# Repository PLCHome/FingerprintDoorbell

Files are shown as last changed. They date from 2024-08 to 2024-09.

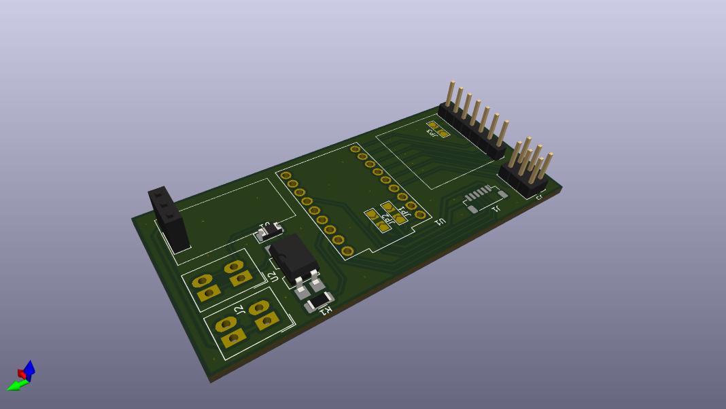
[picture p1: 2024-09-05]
PCBprints/Fingerprint_doorbell.jpg

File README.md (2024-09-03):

# FingerprintVoipDoorbell

## What is FingerprintVoipDoorbell?
It's more or less a doorbell with the ability to scan finger prints or a fingerprint reader with the ability to act as doorbell, depending on your perspective ;-). In addition, if your fingerprints are unknown, you can call and speak to you. Carry out additional actions using telephone keys. The number can be changed to the cell phone if the alarm system is armed, for example. And then when it's the postman the garage opens over the phone using e.g. * or something like that.

But lets speak some images:






## How does it work?
If you put your finger on the sensor the system looks for a matching fingerprint. If it doesn't find one, it rings the bell (MQTT message is published and an GPIO pin is set to high). The system also starts a phone call to a stored number. If a call is made, MQTT messages can be triggered via the number keys on the phone, which in combination with home automation solution (like OpenHAB, ioBroker, Home Assistant...) can be used to open a garage door for the postman to drop off packages, for example, or a smart lock for the child without a key.
If a match was found, the matching finger ID together with a name and confidence will be published as MQTT messagage. In combination with a home automation solution (like OpenHAB, ioBroker, Home Assistant...) you can then trigger your door opener or smart lock. You can also define actions depending on the finger that was detected, like left thumb opens front door, right thumb opens garage, middle finger...

## Features 

### voip:
- Switching off the voip via MQTT (no calls e.g. at night)
- Internal/external number switching via MQTT (e.g. when alarm system is armed/disarmed)
- Ending a call that has not been established via MQTT, e.g. when the door is opened.
- Ending the call when the door is opened.
- Sending key presses via MQTT during an existing telephone call. (e.g. to open the garage)

### fingerprint:
- Management of up to 100 fingers from different people
- Sending the number and recognition code of the recognized finger
- Triggering an output to switch a relay to trigger the alarm if no finger is recognized.
- Starting a call via VoIP if no finger is recognized.
- Ending the call again if the finger is recognized

## Is it from me?
This implementation is not mine alone, it was put together from different branches and revised a little.
- It is an fork on the FingerprintDoorBell from Frickelzeugs:
    
    https://github.com/frickelzeugs/FingerprintDoorbell

- The changes from TheMaskedDeveloper were also adopted for MQTT and the color in the ring.
    
    https://github.com/TheMaskedDeveloper/FingerprintDoorbell/tree/master

- It got the sources and circuitry from Voip Doorbell from Jens Weißkopf for call initiation and audio:

    https://github.com/weisskopfjens/esp32voipdoorbell

    This is based on:
    sip.cpp copyright (c) 2018 Juergen Liegner

      https://www.mikrocontroller.net/topic/444994

Many thanks to everyone for being able to implement this so quickly. It was easy going because of your great work.

## What do I need?
- fingerprint reader Grow R503
- microphone inmp 441
- amplifier max98357 i2s 3w
- speakers with 3w
- an ESP32 microcontroller (I would prefer the mini-version, because of it's compact size).

# How to build the hardware
## Wiring

|ESP32 GPIO | Connected to | notes |
|---|---|---|
|I2S Amplifier| | |
|14 | BCLK | |
|12 | LRC | |
|27 | DIN | |
|I2S Mic | | |
|26 | BCKL SCK | |
|25 | LRCL WS | |
|33 | DOUT SD | |
|Bell | | |
|19 | Ring 2sec. | |
|R503 | | |
|17 | RXD R503 | |
|16 | TXD R503 | |
|5 | WAKEUP R503  | |

Example R503:



I would not solder the cables directly to the ESP32 but recommend using a connector between ESP32 and Sensor. Otherwise, the cables must first be fed through the 25mm hole for the sensor and then soldered on. Replacing the Sensor will be a pain then. The original plug used on the sensor is a 6-pin Micro JST SH 1.00mm but it'll be fine to use any other 6-pin connector that you have on hand if you replace both sides.

Just as an inpiration:



I made a small shield board for the ESP32 mini that contains a 6 pin Micro JST SH 1.00mm socket, a DC-DC step down converter and some screw terminals for the power supply (in my case 24V DC). So I'm now able to easily replace the sensor or ESP32 without touching my soldering iron.

Caution: Please do not forget to ground the sensor housing. Otherwise it can lead to unexpected restarts or even damages the ESP32 if you are electrostatically charged. I had occasional restarts when touching the sensor after I was electrostatically charged from the floor mats in the car.

# Flashing the firmware
## Method 1: use precompiled binaries
To flash the ESP32 with the precompiled binaries you can use the python based esptool from espressif. You'll need a running Python environment on your system, so get Python first here if you don't already have it: [Python download](https://www.python.org/downloads/)

After python is available run the following command in your shell/cmd to install esptool:
```
pip install esptool
```
If there is a `command not found: pip` error but you have installed Python try to use pip3 insted of pip.
```
pip3 install esptool
```

Now esptool should be available in your shell/cmd. Check it by running:
```
esptool.py
```

Now that esptool.py is available you can continue to flash the firmware. To start you will need 5 files:

- bootloader_dio_40m.bin
- boot_app0.bin
- partitions.bin

download [here](doc/bootloader.zip)

- firmware.bin
- spiffs.bin

contained in the [Release packages](releases)

### Flashing
Copy all 5 files in a local folder, open your command line/shell, navigate to this folder and execute:

```
esptool.py --chip esp32 --baud 460800 --before default_reset --after hard_reset write_flash -z --flash_mode dio --flash_freq 40m --flash_size detect 0x1000 bootloader_dio_40m.bin 0x8000 partitions.bin 0xe000 boot_app0.bin 0x10000 firmware.bin 2686976 spiffs.bin
```

If everything has worked your output should look something like this:

```
esptool.py v3.2
Found 2 serial ports
Serial port COM4
Connecting....
Chip is ESP32-D0WDQ6 (revision 1)
Features: WiFi, BT, Dual Core, 240MHz, VRef calibration in efuse, Coding Scheme None
Crystal is 40MHz
MAC: 9c:9c:1f:c7:ac:a0
Uploading stub...
Running stub...
Stub running...
Changing baud rate to 460800
Changed.
Configuring flash size...
Auto-detected Flash size: 4MB
Flash will be erased from 0x00001000 to 0x00005fff...
Flash will be erased from 0x00008000 to 0x00008fff...
Flash will be erased from 0x0000e000 to 0x0000ffff...
Flash will be erased from 0x00010000 to 0x00121fff...
Flash will be erased from 0x00290000 to 0x003fffff...
Compressed 17104 bytes to 11191...
Wrote 17104 bytes (11191 compressed) at 0x00001000 in 0.6 seconds (effective 225.1 kbit/s)...
Hash of data verified.
Compressed 3072 bytes to 128...
Wrote 3072 bytes (128 compressed) at 0x00008000 in 0.1 seconds (effective 300.7 kbit/s)...
Hash of data verified.
Compressed 8192 bytes to 47...
Wrote 8192 bytes (47 compressed) at 0x0000e000 in 0.1 seconds (effective 463.9 kbit/s)...
Hash of data verified.
Compressed 1119504 bytes to 666873...
Wrote 1119504 bytes (666873 compressed) at 0x00010000 in 16.1 seconds (effective 555.0 kbit/s)...
Hash of data verified.
Compressed 1507328 bytes to 36014...
Wrote 1507328 bytes (36014 compressed) at 0x00290000 in 7.5 seconds (effective 1599.3 kbit/s)...
Hash of data verified.

Leaving...
Hard resetting via RTS pin...
```

Your device should now boot up and the LED ring should start flashing slowly red ("breathing") to signal that it's currently in WiFi Config mode. Proceed with the configuration of the device.

## Method 2: build and flash with Visual Studio Code and PlattformIO
Method 1 is the prefered way if you just want a ready to use version of your FingerprintVoipDoorbell. But if you want to build it on your own or maybe modify the code in some way to fit your needs please follow the instructions below. I don't want to go into details here and assume that you already have experience with IDEs or using Git repos:
* Download and install [Visual Studio Code and PlattformIO Extension](https://platformio.org/platformio-ide).
* Install [Git](https://git-scm.com/downloads) if you don't have already
* Clone this GitHub repo and open the project workspace in VS Code (you can do this in one step from within VS Code)
* Open the PlatformIO extension from the left sided toolbar and from the "Project Tasks" tree choose
  * esp32doit-devkit-v1 -> General -> Build (creates firmware.bin)
  * esp32doit-devkit-v1 -> Platform -> Build Filesystem Image (creates spiffs.bin containing HTML and CSS files)
* if the build finishes successfully you can start uploading to your ESP32 by using the following tasks
  * esp32doit-devkit-v1 -> General -> Upload
  * esp32doit-devkit-v1 -> Platform -> Upload Filesystem Image

# Configuration
## WiFi Connection
If no WiFi settings are configured (e.g. on a fresh install) the device will automatically boot into WiFi configuration mode (LED ring is breathing red). Once your WiFi connection is configured the device will never enter WiFi config mode again, even if the WiFi is not available or it cannot connect because of errors. If you later want to enter WiFi configuration mode again you have to press and hold your finger at least 10s on the sensor while powering on the device (or trigger a reboot through WebUI). 

When in WiFi config mode FingerprintVoipDoorbell will act as an AccessPoint an creates it's own Network with the Name "FingerprintVoipDoorbell-Config". Connect to this network with your PC/Mobile and Password "12345678". You should then get a "captive portal" notification, which you should bring you to the browser with the WiFi config already open. If the captive portal thing does not work please open a browser manually and visit "http://192.168.4.1".



Enter your settings and click "Save and restart" to bring the device back to normal operation mode. If everything had worked the LED ring should first flash blue while bootup and starts breathing blue if connection to your WiFi is running. When connected to your WiFi the WebUI of Fingerprintdoorbell should be available under http://fingerprintdoorbell (if you used the default hostname in WiFi configuration). Now you can start enrolling ("teaching") your fingerprints.

## Managing fingerprints
The sensor has the capacity for storing up to 200 fingerprints. Theses memory slots are used as ID together with a name to increase human readability. To enroll new fingerprints enter a ID and name (optional) in the "Add/Replace fingerprint" section and click "Start enrollment". Now the system asks you to place and lift your finger to the sensor for 5 times. The 5 passes of scanning helps the sensor to improve its recognition rate. Don't try to vary your placing/position too much, because the enrollment process may fail if the 5 preceeding scans differ too much from each other and cannot be combined to one fingerprint template.



If enrollment has completed successfull you can now test if your fingerprint matches.

## Configure MQTT connection
Matching fingerprints (and also ring events) are published as messages to your MQTT broker at certain topics. For this you will have to configure your MQTT Broker settings in FingerprintVoipDoorbell. If your broker does not need authentification by username and password just leave this fields empty. You can also specify a custom root topic under which FingerprintVoipDoorbell publishes its messages or leave the default "fingerprintVoipDoorbell" if you're fine with that.



| MQTT Topic | Action | Values | Comment |
| --- | --- | --- | --- |
| fingerprintVoipDoorbell/ring | publish | "off" by default | On a ring event switching to "on" for 1s | 
| fingerprintVoipDoorbell/matchId | publish | "-1" by default |If a match was found the value holds the matching id (e.g. "27") for 3s | 
| fingerprintVoipDoorbell/matchName | publish | "" by default | If a match was found the value holds the matching name for 3s | 
| fingerprintVoipDoorbell/matchConfidence  | publish | "" by default | If a match was found the value holds the conficence (number between "1" and "400", 1=low, 400=very high) for 3s |
| fingerprintVoipDoorbell/phoneSignal  | publish | "0"-"9", "*", "#"  | The phone buttons are pressed when a call is in progress.|
| fingerprintVoipDoorbell/phoneSignalDuration  | publish | "100" in ms | The time it takes to press a button on VoIP telephones is normally 100ms|
| fingerprintVoipDoorbell/ignoreTouchRing  | subscribe | "on", "off" | Read by FingerprintVoipDoorbell and enables/disables the touch ring (see FAQ below for details) |
| fingerprintVoipDoorbell/hangup  | subscribe | "hangup" |Hanging up the phone when talking or ringing. E.g. when the door is opened. |
| fingerprintVoipDoorbell/useNumber  | subscribe | "intern", "extren", "nocall" |Changing the phone number, for example, to external when the alarm system is armed or to off at night so that only the bell does not ring. |

## Advanced Actions
### Firmware Update
If you've managed to walk the bumpy path of flashing the firmware on the ESP32 for the first time, dont't worry: every further firmware update will be a piece of cake. FingerprintVoipDoorbell is using the really cool Library [AsyncElegantOTA](https://github.com/ayushsharma82/AsyncElegantOTA) to make this as handy as possible. You don't even have to pull the microcontroller out of the wall and connect it to your computer, because the "OTA" in "AsyncElegantOTA" is for "Over-the-air" updates. All you need to do is to browse to the settings page of the WebUI and hit "Firmware update". In the following Dialog you have to upload 2 files

- firmware.bin for the "Firmware" radio button
- spiffs.bin for the "Filesystem" radio button

Done. Reboot your system to get the new firmware live.

### Pairing a new Sensor
For security reasons the ESP32 and Sensor will be coupled together, so if the sensor is replaced (e.g. an attackers connects his own sensor to the ESP32 with his fingerprints on it) this will be detected. In this case the pairing will be marked as broken and no further match events are sent by MQTT from now on (even if you connect the old sensor again). But keep calm, the doorbell function will still continue to work and ring events are sent by MQTT so you don't miss your long awaited package delivery. You'll see an error message in the log window that requests you to renew the pairing. If the sensor replacement was done by yourself or no attack took place please choose the option "Pairing a new Sensor" to pair the sensor with the ESP32.

### Factory Reset
As the name already says this will delete all your settings and fingerprints from the device. You'll have a blank device in WiFi Config mode when choosing this option. Be careful!

# FAQ
## What does the different colors/blinking styles of the LED ring mean?
|LED ring color| sequence | Meaning | 
| --- | --- | --- |
| red | permanent | System is in error state |
| red | breathing | System in WiFi config mode |
| red | flashing  | Finger on sensor detected (no match found yet) |
| blue | permanent | System ready (touch ring ignored) |
| blue | breathing | System ready (touch ring active) |
| blue | flashing | System startup (not ready yet) |
| purple | solid | Fingerprint match found or when in enrollment mode this means pass is finished, lift your finger |
| purple | flashing | Enrollment active (waiting for finger) |

## What is the MQTT topic "fingerprintVoipDoorbell/ignoreTouchRing" for and how to use it?
If your sensor is mounted in a dry environment and cannot be hit by rain you can skip this section. Otherwise please read further. The sensor consists mainly of two parts: the black sensor surface and a metal ring divided by the led ring around the sensor surface. The sensor surface will only recognize a finger touch if the larger part of the finger was on the sensor and not only a small tip. Also only short touches are not recognizes, because no image could be captured in this short timespan. Because a visitor who just wants to ring the bell doesn't pay particular attention to putting his finger completely on the sensor, I do not only evaluate the image sensor itself, but also consider the finger detection signal (pin 5) the sensor is providing. This signal is already triggered if you slightly touch the sensor and even if you only touch the metal ring and not yet the sensor surface. 

This ring is a capacitive touch sensor that works similar to the touch display of your smartphone. And if you may know touch displays and rain drops are not best friends, because they can lead to false inputs. This will usually be a problem if your sensor is mounted in a place exposed to rain and even if it's mounted under the roof overhang it may be hit by horizontal rain during a storm and causing false ring events. And believe me: your wife will not be happy if the storm rings on your door at 3 AM ;-)

So after this experience I could have added an option to disable this ring permanent in the settings but I decided to go another way and make this option conditional. Why? Because in >95% of the cases I really want this high sensitivity of the sensor, just not on stormy and rainy days. Fortunately I already had the current weather conditions available in my smart home via a rain sensor. So I added the MQTT topic "fingerprintVoipDoorbell/ignoreTouchRing" which can be set to "on" or "off". In my case OpenHAB sets this value to "on" when it's raining and wind speed is over a certain level. Since then I have had no more problems with disturbing the peace at night.

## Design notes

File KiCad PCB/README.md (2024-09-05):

# FingerprintVoipDoorbell KiCad PCB

## What is KiCad PCB

Kicad PCB is a program for designing printed circuit boards. We used to use Eagle but that is now obsolete.

Download KiCad PCB from

https://www.kicad.org/

## Libraries

To add project specific libraries use `Settings` `Manage Symbol Libraries` and `Manage Foodprint Libraries` respectively go to prohekt pibarys and add the libraries from the `lib.pritty` folder.

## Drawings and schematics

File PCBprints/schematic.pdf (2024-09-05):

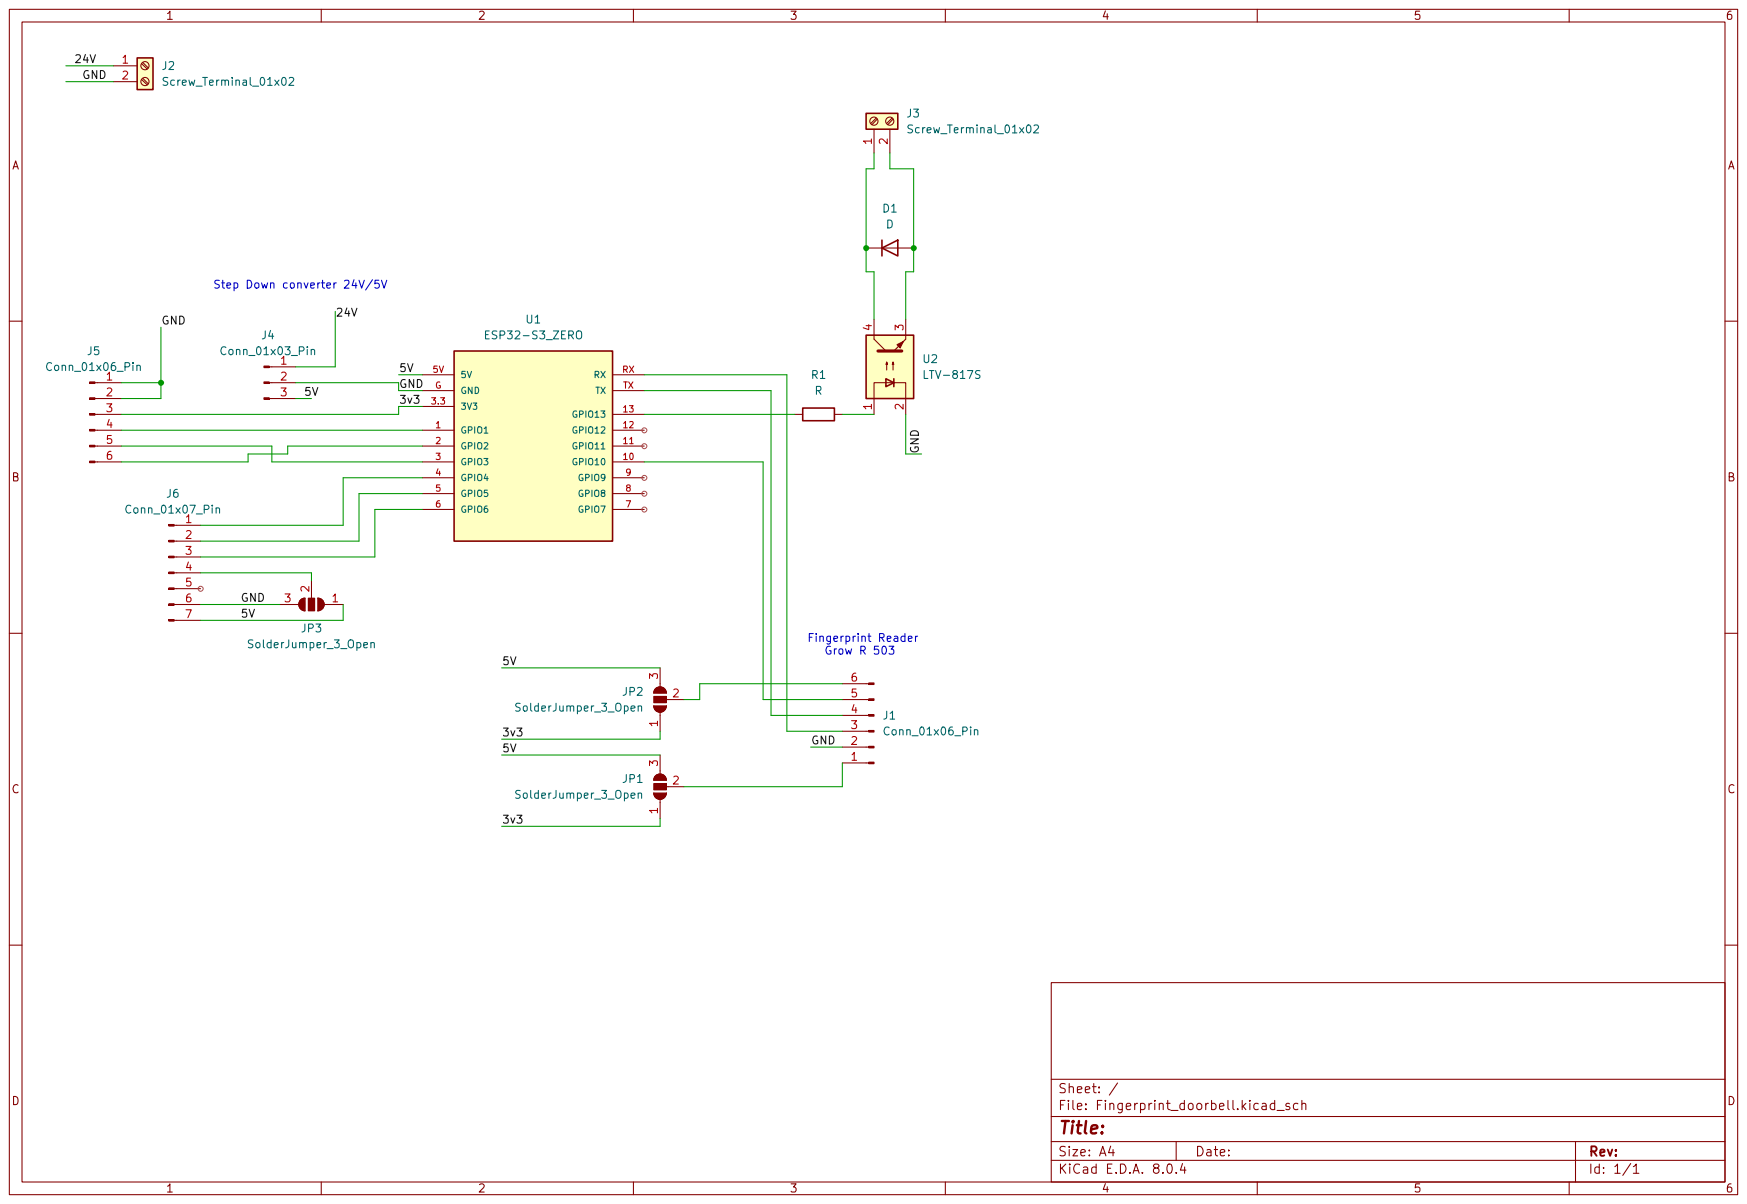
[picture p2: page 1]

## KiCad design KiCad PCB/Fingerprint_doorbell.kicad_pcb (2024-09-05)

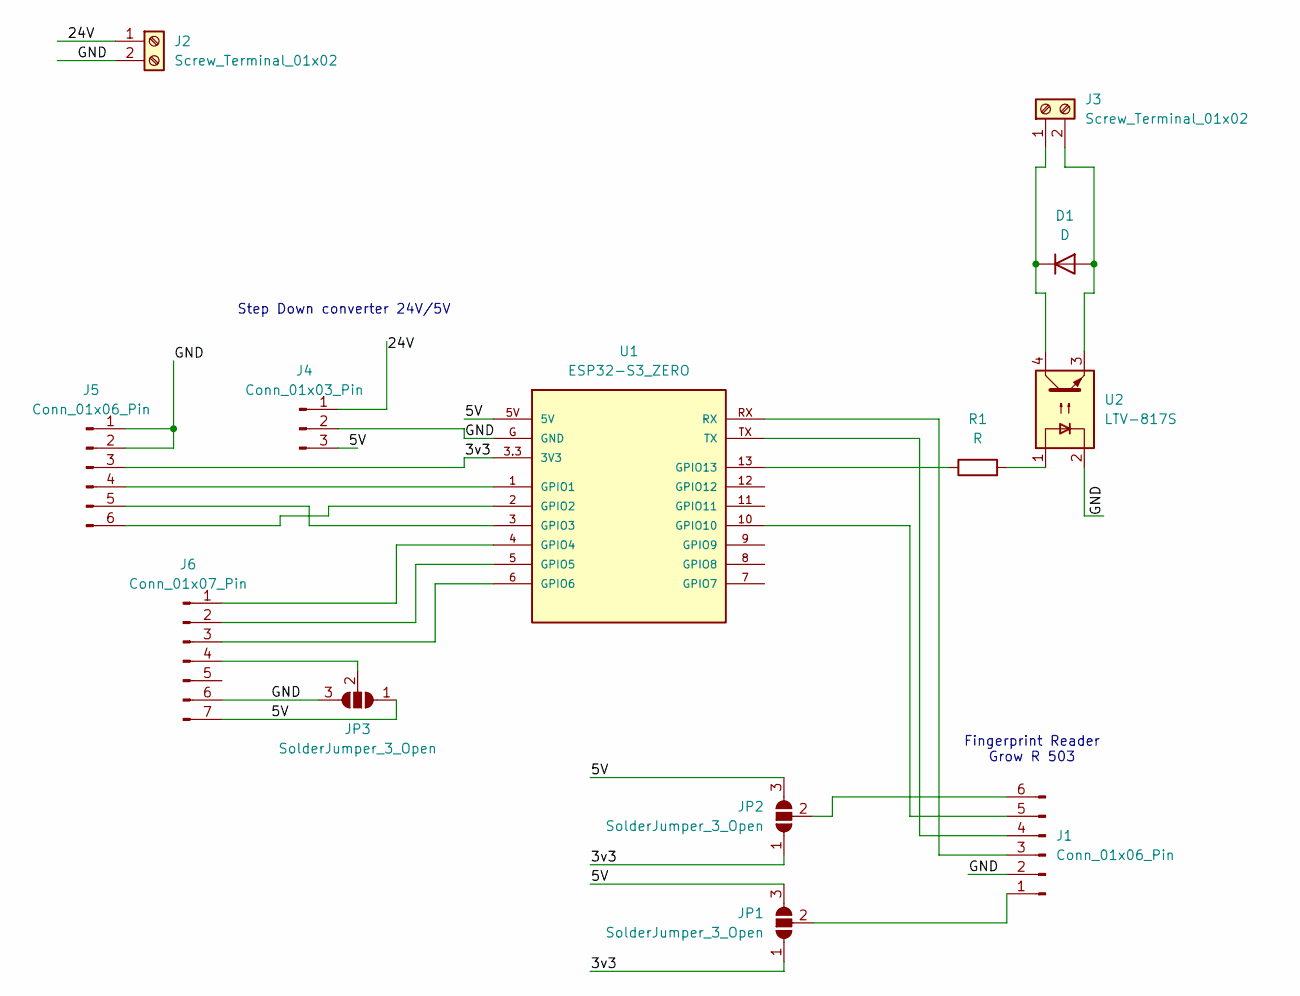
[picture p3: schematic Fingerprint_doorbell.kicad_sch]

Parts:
D1: D; D_1206_3216Metric_Pad1.42x1.75mm_HandSolder
J1: Conn_01x06_Pin; JST_SH_BM06B-SRSS-TB_1x06-1MP_P1.00mm_Vertical
J2, J3: Screw_Terminal_01x02; TerminalBlock_Phoenix_PTSM-0,5-2-2.5-H-THR_1x02_P2.50mm_Hor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
J4: Conn_01x03_Pin; PinSocket_1x03_P2.54mm_Vertical
J5: Conn_01x06_Pin; PinHeader_2x03_P2.54mm_Vertical
J6: Conn_01x07_Pin; PinHeader_1x07_P2.54mm_Vertical
JP1, JP2, JP3: SolderJumper_3_Open; SolderJumper-3_P2.0mm_Open_TrianglePad1.0x1.5mm_NumberLabels
R1: R; R_1206_3216Metric_Pad1.30x1.75mm_HandSolder
U1: ESP32-S3_ZERO; MODULE_ESP32-S3_ZERO
U2: LTV-817S; SMDIP-4_W9.53mm

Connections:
/3v3: J5.3, JP1.1 (A), JP2.1 (A), U1.3.3 (3V3)
/5V: J4.3, J6.7, JP1.3 (B), JP2.3 (B), JP3.1 (A), U1.5V
/24V: J2.1, J4.1
/GND: J1.2, J2.2, J4.2, J5.1, J5.2, J6.6, JP3.3 (B), U1.G (GND), U2.2
unnamed: D1.2 (A), J3.2, U2.3
unnamed: D1.1 (K), J3.1, U2.4
unnamed: J1.1, JP1.2 (C)
unnamed: J1.3, U1.RX
unnamed: J1.4, U1.TX
unnamed: J1.5, U1.10 (GPIO10)
unnamed: J1.6, JP2.2 (C)
unnamed: J5.4, U1.1 (GPIO1)
unnamed: J5.5, U1.3 (GPIO3)
unnamed: J5.6, U1.2 (GPIO2)
unnamed: J6.1, U1.4 (GPIO4)
unnamed: J6.2, U1.5 (GPIO5)
unnamed: J6.3, U1.6 (GPIO6)
unnamed: J6.4, JP3.2 (C)
unnamed: R1.2, U2.1
unnamed: R1.1, U1.13 (GPIO13)

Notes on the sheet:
Step Down converter 24V/5V
Fingerprint Reader Grow R 503

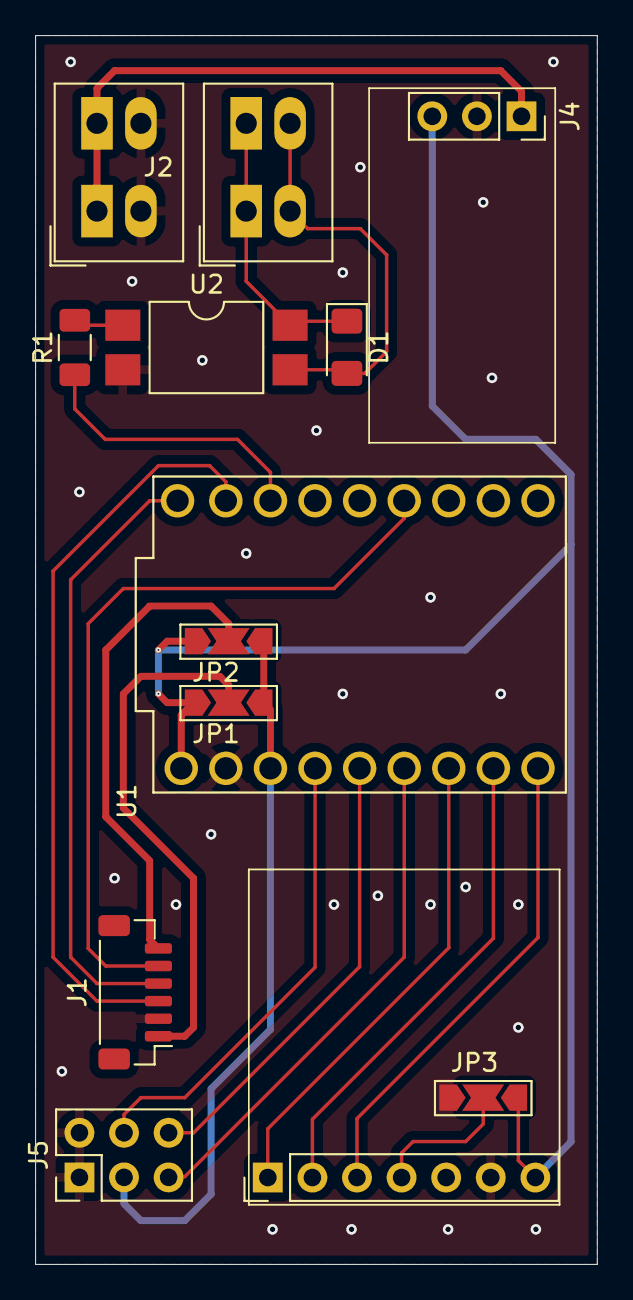
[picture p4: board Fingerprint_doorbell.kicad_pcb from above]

Board: 2 copper layers, 32.0 x 70.0 mm, 13 parts (0 on the bottom side), 20 nets.

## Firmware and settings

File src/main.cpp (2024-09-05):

/***************************************************
  Main of FingerprintVoipDoorbell 
 ****************************************************/

#include <WiFi.h>
#include <DNSServer.h>
#include <time.h>
#include <ElegantOTA.h>
#include <SPIFFS.h>
#include <PubSubClient.h>
#include <ESPAsyncWebServer.h>
#include "FingerprintManager.h"
#include "SettingsManager.h"
#include "global.h"
#include "voipphone.h"
#include "myTimer.h"

enum class Mode { scan, scanbreak, enroll, wificonfig, maintenance };

const char* VersionInfo = "0.6";

// ===================================================================================================================
// Caution: below are not the credentials for connecting to your home network, they are for the Access Point mode!!!
// ===================================================================================================================
const char* WifiConfigSsid = "FingerprintVoipDoorbell-Config"; // SSID used for WiFi when in Access Point mode for configuration
const char* WifiConfigPassword = "12345678"; // password used for WiFi when in Access Point mode for configuration. Min. 8 chars needed!
IPAddress   WifiConfigIp(192, 168, 4, 1); // IP of access point in wifi config mode

const char* Selected = "selected"; // For the Webserver!
const char* Checked = "checked"; // For the Webserver!

const long  gmtOffset_sec = 0; // UTC Time
const int   daylightOffset_sec = 0; // UTC Time
//#define DOORBELL_OUTPUT_PIN 19 // pin connected to the doorbell (when using hardware connection instead of mqtt to ring the bell)

#ifdef CUSTOM_GPIOS
  const int   customOutput1 = 18; // not used internally, but can be set over MQTT
  const int   customOutput2 = 26; // not used internally, but can be set over MQTT
  const int   customInput1 = 21; // not used internally, but changes are published over MQTT
  const int   customInput2 = 22; // not used internally, but changes are published over MQTT
  bool customInput1Value = false;
  bool customInput2Value = false;
#endif

const int logMessagesCount = 5;
String logMessages[logMessagesCount]; // log messages, 0=most recent log message
bool shouldReboot = false;
unsigned long wifiReconnectPreviousMillis = 0;
unsigned long mqttReconnectPreviousMillis = 0;

String enrollId;
String enrollName;
Mode currentMode = Mode::scan;

FingerprintManager fingerManager;
SettingsManager settingsManager;
bool needMaintenanceMode = false;

const byte DNS_PORT = 53;
DNSServer dnsServer;
AsyncWebServer webServer(80); // AsyncWebServer  on port 80
AsyncEventSource events("/events"); // event source (Server-Sent events)

WiFiClient espClient;
PubSubClient mqttClient(espClient);
long lastMsg = 0;
char msg[50];
int value = 0;
bool mqttConfigValid = true;

VOIPPhone doorphone;
bool doorphonerunning = false;
char* phonenumber;
char* calldevicename;

Match lastMatch;

void addLogMessage(const String& message) {
  // shift all messages in array by 1, oldest message will die
  for (int i=logMessagesCount-1; i>0; i--)
    logMessages[i]=logMessages[i-1];
  logMessages[0]=message;
}

String getLogMessagesAsHtml() {
  String html = "";
  for (int i=logMessagesCount-1; i>=0; i--) {
    if (logMessages[i]!="")
      html = html + logMessages[i] + "<br>";
  }
  return html;
}

const char* makeMemCStr(String value) {
  char* ptr = new char[value.length() + 1];
  strcpy(ptr, value.c_str());
  return ptr;
}

String getTimestampString(){
  struct tm timeinfo;
  if(!getLocalTime(&timeinfo)){
    Serial.println("Failed to obtain time");
    return "no time";
  }
  
  char buffer[25];
  strftime(buffer,sizeof(buffer),"%Y-%m-%d %H:%M:%S %Z", &timeinfo);
  String datetime = String(buffer);
  return datetime;
}

/* wait for maintenance mode or timeout 5s */
bool waitForMaintenanceMode() {
  needMaintenanceMode = true;
  unsigned long startMillis = millis();
  while (currentMode != Mode::maintenance) {
    if ((millis() - startMillis) >= 5000ul) {
      needMaintenanceMode = false;
      return false;
    }
    delay(50);
  }
  needMaintenanceMode = false;
  return true;
}

// Replaces placeholder in HTML pages
String processor(const String& var){
  if(var == "LOGMESSAGES"){
    return getLogMessagesAsHtml();
  } else if (var == "FINGERLIST") {
    return fingerManager.getFingerListAsHtmlOptionList();
  } else if (var == "HOSTNAME") {
    return settingsManager.getWifiSettings().hostname;
  } else if (var == "VERSIONINFO") {
    return VersionInfo;
  } else if (var == "WIFI_SSID") {
    return settingsManager.getWifiSettings().ssid;
  } else if (var == "WIFI_PASSWORD") {
    if (settingsManager.getWifiSettings().password.isEmpty())
      return "";
    else
      return "********"; // for security reasons the wifi password will not left the device once configured
  } else if (var == "MQTT_SERVER") {
    return settingsManager.getAppSettings().mqttServer;
  } else if (var == "MQTT_USERNAME") {
    return settingsManager.getAppSettings().mqttUsername;
  } else if (var == "MQTT_PASSWORD") {
    return settingsManager.getAppSettings().mqttPassword;
  } else if (var == "MQTT_ROOTTOPIC") {
    return settingsManager.getAppSettings().mqttRootTopic;
  } else if (var == "RINGTIME") {
    return String(settingsManager.getAppSettings().ringtime);
  } else if (var == "NTP_SERVER") {
    return settingsManager.getAppSettings().ntpServer;
  }  else if (var == "TOUCH_RING_ACTIVE_COLOR_1") {
    return (settingsManager.getAppSettings().touchRingActiveColor == 1) ? Selected : "";
  }  else if (var == "TOUCH_RING_ACTIVE_COLOR_2") {
    return (settingsManager.getAppSettings().touchRingActiveColor == 2) ? Selected : "";
  }  else if (var == "TOUCH_RING_ACTIVE_COLOR_3") {
    return (settingsManager.getAppSettings().touchRingActiveColor == 3) ? Selected : "";
  }  else if (var == "TOUCH_RING_ACTIVE_COLOR_4") {
    return (settingsManager.getAppSettings().touchRingActiveColor == 4) ? Selected : "";
  }  else if (var == "TOUCH_RING_ACTIVE_COLOR_5") {
    return (settingsManager.getAppSettings().touchRingActiveColor == 5) ? Selected : "";
  }  else if (var == "TOUCH_RING_ACTIVE_COLOR_6") {
    return (settingsManager.getAppSettings().touchRingActiveColor == 6) ? Selected : "";
  }  else if (var == "TOUCH_RING_ACTIVE_COLOR_7") {
    return (settingsManager.getAppSettings().touchRingActiveColor == 7) ? Selected : "";
  }  else if (var == "TOUCH_RING_ACTIVE_SEQUENCE_4") {
    return (settingsManager.getAppSettings().touchRingActiveSequence == 4) ? Checked : "";
  }  else if (var == "TOUCH_RING_ACTIVE_SEQUENCE_3") {
    return (settingsManager.getAppSettings().touchRingActiveSequence == 3) ? Checked : "";
  }  else if (var == "TOUCH_RING_ACTIVE_SEQUENCE_1") {
    return (settingsManager.getAppSettings().touchRingActiveSequence == 1) ? Checked : "";
  }  else if (var == "TOUCH_RING_ACTIVE_SEQUENCE_2") {
    return (settingsManager.getAppSettings().touchRingActiveSequence == 2) ? Checked : "";
  }  else if (var == "SCAN_COLOR_1") {
    return (settingsManager.getAppSettings().scanColor == 1) ? Selected : "";
  }  else if (var == "SCAN_COLOR_2") {
    return (settingsManager.getAppSettings().scanColor == 2) ? Selected : "";
  }  else if (var == "SCAN_COLOR_3") {
    return (settingsManager.getAppSettings().scanColor == 3) ? Selected : "";
  }  else if (var == "SCAN_COLOR_4") {
    return (settingsManager.getAppSettings().scanColor == 4) ? Selected : "";
  }  else if (var == "SCAN_COLOR_5") {
    return (settingsManager.getAppSettings().scanColor == 5) ? Selected : "";
  }  else if (var == "SCAN_COLOR_6") {
    return (settingsManager.getAppSettings().scanColor == 6) ? Selected : "";
  }  else if (var == "SCAN_COLOR_7") {
    return (settingsManager.getAppSettings().scanColor == 7) ? Selected : "";
  }  else if (var == "MATCH_COLOR_1") {
    return (settingsManager.getAppSettings().matchColor == 1) ? Selected : "";
  }  else if (var == "MATCH_COLOR_2") {
    return (settingsManager.getAppSettings().matchColor == 2) ? Selected : "";
  }  else if (var == "MATCH_COLOR_3") {
    return (settingsManager.getAppSettings().matchColor == 3) ? Selected : "";
  }  else if (var == "MATCH_COLOR_4") {
    return (settingsManager.getAppSettings().matchColor == 4) ? Selected : "";
  }  else if (var == "MATCH_COLOR_5") {
    return (settingsManager.getAppSettings().matchColor == 5) ? Selected : "";
  }  else if (var == "MATCH_COLOR_6") {
    return (settingsManager.getAppSettings().matchColor == 6) ? Selected : "";
  }  else if (var == "MATCH_COLOR_7") {
    return (settingsManager.getAppSettings().matchColor == 7) ? Selected : "";
  }  else if (var == "ENROLLTEMPLATES") {
    return String(settingsManager.getAppSettings().enrollTemplates);
  }  else if (var == "SIP_IP") {
    return settingsManager.getAppSettings().sip_ip;
  }  else if (var == "SIP_USER") {
    return settingsManager.getAppSettings().sip_user;
  }  else if (var == "SIP_PASS") {
    return settingsManager.getAppSettings().sip_pass;
  }  else if (var == "SIPTIMEOUTDIAL") {
    return String(settingsManager.getAppSettings().sipTimeoutDial);
  }  else if (var == "SIPTIMEOUTCONNECT") {
    return String(settingsManager.getAppSettings().sipTimeoutConnect);
  }  else if (var == "AMP_GAIN") {
    return String(settingsManager.getAppSettings().amp_gain);
  }  else if (var == "MIC_GAIN") {
    return String(settingsManager.getAppSettings().mic_gain);
  }  else if (var == "ECHOCOMPENSATION") {
    return (settingsManager.getAppSettings().echocompensation) ? Checked : "";
  }  else if (var == "ECHOTHRESHOLD") {
    return String(settingsManager.getAppSettings().echothreshold);
  }  else if (var == "ECHODAMPING") {
    return String(settingsManager.getAppSettings().echodamping);
  } else if (var == "CALLDEVICENAME") {
    return settingsManager.getAppSettings().calldevicename;
  } else if (var == "PHONENUMBER") {
    return settingsManager.getAppSettings().phonenumber;
  } else if (var == "PHONENUMBER2") {
    return settingsManager.getAppSettings().phonenumber2;
  }
  return String();
}

// send LastMessage to websocket clients
void notifyClients(String message) {
  String messageWithTimestamp = "[" + getTimestampString() + "]: " + message;
  Serial.println(messageWithTimestamp);
  addLogMessage(messageWithTimestamp);
  events.send(getLogMessagesAsHtml().c_str(),"message",millis(),1000);
  
  String mqttRootTopic = settingsManager.getAppSettings().mqttRootTopic;
  mqttClient.publish((String(mqttRootTopic) + "/lastLogMessage").c_str(), message.c_str());
}

void updateClientsFingerlist(String fingerlist) {
  Serial.println("New fingerlist was sent to clients");
  events.send(fingerlist.c_str(),"fingerlist",millis(),1000);
}


bool doPairing() {
  String newPairingCode = settingsManager.generateNewPairingCode();

  if (fingerManager.setPairingCode(newPairingCode)) {
    AppSettings settings = settingsManager.getAppSettings();
    settings.sensorPairingCode = newPairingCode;
    settings.sensorPairingValid = true;
    settingsManager.saveAppSettings(settings);
    notifyClients("Pairing successful.");
    return true;
  } else {
    notifyClients("Pairing failed.");
    return false;
  }

}


bool checkPairingValid() {
  AppSettings settings = settingsManager.getAppSettings();

  if (!settings.sensorPairingValid) {
    if (settings.sensorPairingCode.isEmpty()) {
      // first boot, do pairing automatically so the user does not have to do this manually
      return doPairing();
    } else {
      Serial.println("Pairing has been invalidated previously.");   
      return false;
    }
  }

  String actualSensorPairingCode = fingerManager.getPairingCode();
  //Serial.println("Awaited pairing code: " + settings.sensorPairingCode);
  //Serial.println("Actual pairing code: " + actualSensorPairingCode);

  if (actualSensorPairingCode.equals(settings.sensorPairingCode))
    return true;
  else {
    if (!actualSensorPairingCode.isEmpty()) { 
      // An empty code means there was a communication problem. So we don't have a valid code, but maybe next read will succeed and we get one again.
      // But here we just got an non-empty pairing code that was different to the awaited one. So don't expect that will change in future until repairing was done.
      // -> invalidate pairing for security reasons
      AppSettings settings = settingsManager.getAppSettings();
      settings.sensorPairingValid = false;
      settingsManager.saveAppSettings(settings);
    }
    return false;
  }
}


bool initWifi() {
  // Connect to Wi-Fi
  WifiSettings wifiSettings = settingsManager.getWifiSettings();
  WiFi.mode(WIFI_STA);
  WiFi.config(INADDR_NONE, INADDR_NONE, INADDR_NONE, INADDR_NONE);
  WiFi.setHostname(makeMemCStr(wifiSettings.hostname)); //define hostname
  WiFi.begin(makeMemCStr(wifiSettings.ssid), makeMemCStr(wifiSettings.password));
  int counter = 0;
  while (WiFi.status() != WL_CONNECTED) {
    delay(1000);
    Serial.println("Waiting for WiFi connection...");
    counter++;
    if (counter > 30)
      return false;
  }
  Serial.println("Connected!");

  // Print ESP32 Local IP Address
  Serial.println(WiFi.localIP());
  Serial.println(WiFi.dnsIP());

  return true;
}

void initWiFiAccessPointForConfiguration() {
  WiFi.softAPConfig(WifiConfigIp, WifiConfigIp, IPAddress(255, 255, 255, 0));
  WiFi.softAP(WifiConfigSsid, WifiConfigPassword);

  // if DNSServer is started with "*" for domain name, it will reply with
  // provided IP to all DNS request
  dnsServer.start(DNS_PORT, "*", WifiConfigIp);

  Serial.print("AP IP address: ");
  Serial.println(WifiConfigIp); 
}
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
void loop()
{
  // shouldReboot flag for supporting reboot through webui
  if (shouldReboot) {
    reboot();
  }
  
  // First see if there is an action
  myTimerloop();

  // Reconnect handling
  if (currentMode != Mode::wificonfig)
  {
    unsigned long currentMillis = millis();
    // reconnect WiFi if down for 30s
    if ((WiFi.status() != WL_CONNECTED) && (currentMillis - wifiReconnectPreviousMillis >= 30000ul)) {
      Serial.println("Reconnecting to WiFi...");
      WiFi.disconnect();
      WiFi.reconnect();
      wifiReconnectPreviousMillis = currentMillis;
    }

    // reconnect mqtt if down
    if (!settingsManager.getAppSettings().mqttServer.isEmpty()) {
      if (!mqttClient.connected() && (currentMillis - mqttReconnectPreviousMillis >= 30000ul)) {
        connectMqttClient();
        mqttReconnectPreviousMillis = currentMillis;
      }
      mqttClient.loop();
    }

    if( !doorphonerunning) {
      notifyClients(String("Online. Starting sip modul... ") + settingsManager.getAppSettings().sip_ip);
      char* sip_ip = strcpy((char*)malloc(settingsManager.getAppSettings().sip_ip.length()+1), 
                                          settingsManager.getAppSettings().sip_ip.c_str());
      char* sip_user = strcpy((char*)malloc(settingsManager.getAppSettings().sip_user.length()+1), 
                                          settingsManager.getAppSettings().sip_user.c_str());
      char* sip_pass = strcpy((char*)malloc(settingsManager.getAppSettings().sip_pass.length()+1), 
                                          settingsManager.getAppSettings().sip_pass.c_str());
      phonenumber = strcpy((char*)malloc(settingsManager.getAppSettings().phonenumber.length()+1), 
                                          settingsManager.getAppSettings().phonenumber.c_str());
      calldevicename = strcpy((char*)malloc(settingsManager.getAppSettings().calldevicename.length()+1), 
                                          settingsManager.getAppSettings().calldevicename.c_str());
      if(int result = doorphone.begin(sip_ip,
                                      sip_user,
                                      sip_pass)==VOIPPHONE_OK) {
        doorphone.setAmpGain(settingsManager.getAppSettings().amp_gain);
        doorphone.setMicGain(settingsManager.getAppSettings().mic_gain);
        doorphone.setEchoCompensation(settingsManager.getAppSettings().echocompensation,
                                      settingsManager.getAppSettings().echothreshold,
                                      settingsManager.getAppSettings().echodamping);
        doorphone.setSignalCallback(signalCallback);
        Serial.println("[OK]");
      } else {
        notifyClients(String("Cant start sip modul! ERROR CODE:") + result);
      }
      doorphonerunning = true;
    }
    doorphone.loop();
  }


  // do the actual loop work
  switch (currentMode)
  {
  case Mode::scan:
    if (fingerManager.connected)
      doScan();
    break;
  case Mode::scanbreak:
    break;
  case Mode::enroll:
    doEnroll();
    currentMode = Mode::scan; // switch back to scan mode after enrollment is done
    break;
  
  case Mode::wificonfig:
    dnsServer.processNextRequest(); // used for captive portal redirect
    break;

  case Mode::maintenance:
    // do nothing, give webserver exclusive access to sensor (not thread-safe for concurrent calls)
    break;

  }

  // enter maintenance mode (no continous scanning) if requested
  if (needMaintenanceMode)
    currentMode = Mode::maintenance;

  #ifdef CUSTOM_GPIOS
    // read custom inputs and publish by MQTT
    bool i1;
    bool i2;
    i1 = (digitalRead(customInput1) == HIGH);
    i2 = (digitalRead(customInput2) == HIGH);

    String mqttRootTopic = settingsManager.getAppSettings().mqttRootTopic;
    if (i1 != customInput1Value) {
        if (i1)
          mqttClient.publish((String(mqttRootTopic) + "/customInput1").c_str(), "on");      
        else
          mqttClient.publish((String(mqttRootTopic) + "/customInput1").c_str(), "off");      
    }

    if (i2 != customInput2Value) {
        if (i2)
          mqttClient.publish((String(mqttRootTopic) + "/customInput2").c_str(), "on");      
        else
          mqttClient.publish((String(mqttRootTopic) + "/customInput2").c_str(), "off");  
    }

    customInput1Value = i1;
    customInput2Value = i2;

  #endif  

}

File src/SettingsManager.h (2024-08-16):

#ifndef SETTINGSMANAGER_H
#define SETTINGSMANAGER_H

#include <Preferences.h>
#include "global.h"
#include "voipphone.h"

struct WifiSettings {    
    String ssid = "";
    String password = "";
    String hostname = "fingerprintVoipDoorbell";
};

struct AppSettings {
    String mqttServer = "";
    String mqttUsername = "";
    String mqttPassword = "";
    String mqttRootTopic = "fingerprintVoipDoorbell";
    uint8_t ringtime = 1;
    String ntpServer = "pool.ntp.org";
    String sensorPin = "00000000";
    String sensorPairingCode = "";
    int8_t touchRingActiveColor = 2;
    int8_t touchRingActiveSequence = 1;
    int8_t scanColor = 1;
    int8_t matchColor = 3;
    int8_t enrollTemplates = 5;
    bool   sensorPairingValid = false;
    String sip_ip = "";
    String sip_user = "";
    String sip_pass = "";
    uint8_t sipTimeoutDial = 15;
    uint16_t sipTimeoutConnect = 60;
    uint8_t amp_gain = AMP_GAIN;
    uint8_t mic_gain = MIC_GAIN;
    bool   echocompensation = false;
    long   echothreshold = 100;
    uint8_t echodamping = 1;
    String calldevicename = "";
    String phonenumber = "";
    String phonenumber2 = "";
};

class SettingsManager {       
  private:
    WifiSettings wifiSettings;
    AppSettings appSettings;

    void saveWifiSettings();
    void saveAppSettings();

  public:
    bool loadWifiSettings();
    bool loadAppSettings();

    WifiSettings getWifiSettings();
    void saveWifiSettings(WifiSettings newSettings);
    
    AppSettings getAppSettings();
    void saveAppSettings(AppSettings newSettings);

    bool isWifiConfigured();

    bool deleteAppSettings();
    bool deleteWifiSettings();

    String generateNewPairingCode();

};

#endif

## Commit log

2023-10-27 Loop fehlte und Umwandlung von String als Pointer
2023-10-27 hang up (Mqtt beim Türöffenen und bei erkannten Finger)
2023-10-27 favicon
    Setup Design
    Zähler im SIP
    Callback Tastendruck und MQTT für Taste
2023-10-30 Update SettingsManager.h
    fingerprintVoipDoorbell
2023-10-30 Hide MQTT Password
    pin Out
    readme.MD
    added no call
2023-10-30 Ring und Dialtime
2024-08-31 Libaries update auf aktuelle Versionen.
    ESPS3 Copilierung hinzugefügt
    Konstanten für Voip Pin
    espressif32 auf die Aktuelle Verion 6.8.1
    i2c dafür angepasst, Beim Mic ist rechts jetzt rechts
    und dem VSCODE upper case beigebracht
2024-09-05 Fix PCB lib
    [Fingerprint_doorbell-B_Cu.gbr, Fingerprint_doorbell-B_Mask.gbr, Fingerprint_doorbell-B_Paste.gbr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]
2024-09-05 foodprint fixed
    [Fingerprint_doorbell.kicad_sch]
2024-09-05 PIN über PIO
